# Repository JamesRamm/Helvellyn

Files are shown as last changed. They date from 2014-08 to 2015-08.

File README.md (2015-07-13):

Helvellyn
==========

KiCAD schematic and pcb files for the Helvellyn console project.

Helvellyn is a modular, DIY console design by Ramshackle Recording. 
PCB's for various modules will be available from www.ramshacklerecording.com

The backplane PCB for the console is released as an open source project for self-etching/manufacture and improvements, updates etc.

PCB's for the four-module backplane will also be available from Ramshackle Recording.

The Concept
============
The Helvellyn console system is based on the Eurocard and eurorack format and aims to be:

- Modular
- Expandable
- Analogue signal path
- Customisable

Each backplane PCB has space for four 7HP wide eurocard modules, or two 14HP modules.
Modules mate to the backplane via a 32-way DIN connector, which provides the following functionality:

- Two balanced inputs per module (I.e there are allowances for +, - and 0v on each input)
- A direct output (or 2 unbalanced outputs)
- 12 audio buses ('Normal' configuration will be 4 mono auxilliary buses, 3 stereo mix buses and 1 stereo master bus)
- +Ve, -Ve power buses (normally +/-16V)
- Four ground/0V buses (normally used as reference voltage for power, audio, relay/logic power and fader)
- A single, unbalanced output. Normally used to send audio to an external fader.

The backplane can be fixed to a standard 3U Eurorack such as:
http://uk.farnell.com/schroff/24563-131/subrack-3u-175mm-84hp/dp/1370391

With the Helvellyn system, it will be possible to build anything from a single 'lunchbox' rack of individual modules, to a large console with all the usual facilities.

Modules
==========
Ramshackle Recording is actively developing a set of modules which can be used to produce a small-format, high quality mixing desk.
The first modules to be released will be:

- EasyPSU: an 'onboard' PSU for powering a single rack
- Easy69: an easy-to-build high quality EQ, based on the famous Helios type 69.
- ISA-ish: A preamp. Something like the Focusrite ISA, but with modern components.

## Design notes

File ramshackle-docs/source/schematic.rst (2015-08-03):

.. _schematic

Schematic
============

Below is the schematic for the Easy69 module and also the backplane connections for the Helvellyn backplane/motherboard

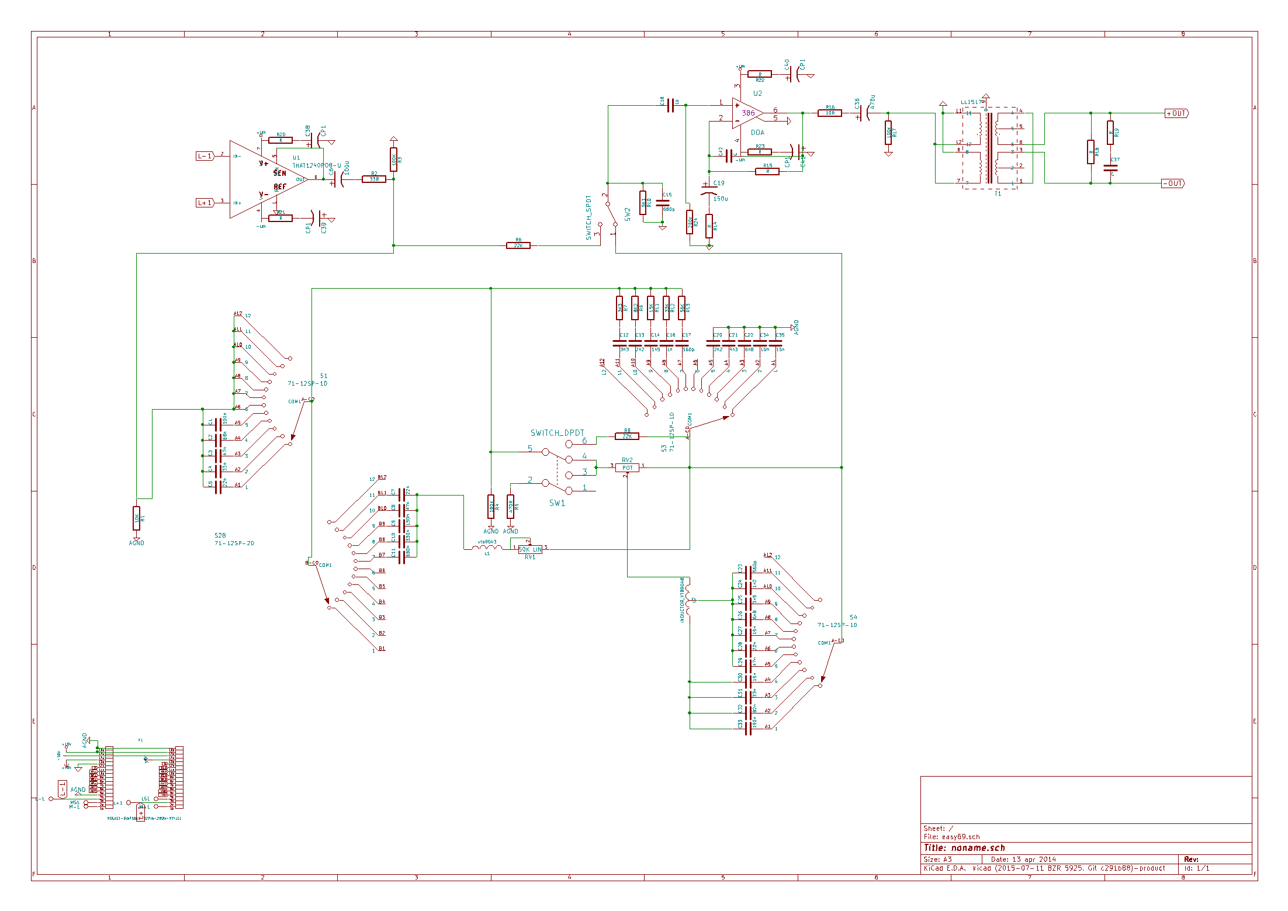
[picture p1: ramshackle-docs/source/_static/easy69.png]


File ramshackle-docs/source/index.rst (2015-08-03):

.. easy69 documentation master file, created by
   sphinx-quickstart on Sun Dec 14 18:03:30 2014.
   You can adapt this file completely to your liking, but it should at least
   contain the root `toctree` directive.

Easy69
==================================

Easy 69 is a 3-band inductor based EQ based on the classic Helios type 69. It is aimed as a relatively simple build with easy-to-find parts. 

Contents:

.. toctree::
   :maxdepth: 2
   
   schematic
   bom
   notes

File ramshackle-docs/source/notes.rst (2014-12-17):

.. _notes

Build Notes
==================================
Before starting anything, you should familiarise yourself with the schematics and board layout.
There are various choices to make when gathering components, such as which transformer and opamp to use. 
This decision will affect the value of some resistors and capacitors.

Opamps
------------------

The resistors R15 and R14 set the makeup gain for the opamp. 
The easy69 has approximately a 15dB insertion loss. Therefore R15 and R14 should be scaled such that 

.. math::
    20log(1 + R15/R14) =~ 15

An example value would be :math:`R15 = 25K` and :math:`R14 = 5K1`. These are good values to choose for 2520-style opamps.
There are of course numerous combinations of R14 and R15 that will give the correct gain and the best values to choose depends upon the opamp.
Usually the manufacturer/designer should be able to give you some kind of indication as to a good pairing.

C42 is a compensation cap, usually in the range 10 - 500pf. Some opamps already include a compensation cap, so you should check the datasheet as to whether this is necessary.

Transformers
------------------
Easy69 can take a Lundahl LL1517, Cinemag XXXX or Edcor XXXX transformer.
The resistor and capacitor XXXX form a zobel network which is required to dampen `ringing`in a transformer.
The correct values are dependent on the transformer and can usually be found via the datasheet or from the manufacturer.

Capacitor ranges: Panasonic ECQE(F) ECQV(?)
ECQE(B)

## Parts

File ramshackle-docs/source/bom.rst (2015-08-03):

.. _bom

Bill Of Materials
=====================

.. _capacitors:
Capacitors
------------
.. csv-table:: 
    :header: "Value", "Quantity", "Ref", "Link", "Note"    

    "560p",	2,	"C17 C23", `Farnell <http://uk.farnell.com/lcr-components/fscex-560pf-1-630v/cap-film-ps-560pf-630v-axial/dp/9520813?ost=9520813>`_,
    "680p",	1,	"C15",`Farnell <http://uk.farnell.com/wima/fkp2d006801d00jssd/cap-film-pp-680pf-100v-rad/dp/1005990?ost=1005990>`_,
    "1n",	1,"C16"
    "1n2",1,"C24","`Farnell <http://uk.farnell.com/wima/fkp2d011001d00hssd/cap-film-pp-1nf-100v-rad/dp/1890176>`_ `Mouser <http://uk.mouser.com/ProductDetail/Kemet/MMK5122J100J01L165TA18/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>`_","Alternately use pll combination of 680p and 560p"
    "1n5",1,"C14",`Farnell <http://uk.farnell.com/wima/fks2d011501a00kssd/cap-film-pet-1-5nf-100v-rad/dp/1005993?ost=1005993>`_
    "2n2",2,"C13 C20",`Farnell <http://uk.farnell.com/wima/fks2d012201a00kssd/cap-film-pet-2-2nf-100v-rad/dp/1005949?ost=1005949>`_,
    "3n3",1,"C12",`Farnell <http://uk.farnell.com/wima/fks2d013301a00kssd/cap-film-pet-3-3nf-100v-rad/dp/1005994?ost=1005994>`_,
    "3n9",1,"C25",`Mouser <http://uk.mouser.com/ProductDetail/Kemet/MMK5392J63J01L165TR18/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>`_,"Alternately use 3.98 = pll combination of 3n3 and 680pf"
    "4n3",1,"C21",`Mouser <http://uk.mouser.com/ProductDetail/Vishay/BFC237516432/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>`_,"Can also use 4n7 farnell #: 1890183	1890183"
    "6n8",2,"C22 C26",`Farnell <http://uk.farnell.com/wima/fks2d016801a00kssd/cap-film-pet-6-8nf-100v-rad/dp/1005997?ost=1005997>`_,
    "10n",1,"C34",`Farnell <http://uk.farnell.com/panasonic-electronic-components/ecqv1h103jl/cap-film-pet-10nf-50v-rad/dp/1669200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>`_,
    "15n",3,"C27 C30 C35",`Farnell <http://uk.farnell.com/panasonic-electronic-components/ecqv1h153jl/cap-film-pet-15nf-50v-rad/dp/1669202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>`_,
    "22n",3,"C5 C7 C28",`Farnell <http://uk.farnell.com/panasonic-electronic-components/ecqv1h223jl/cap-film-pet-22nf-50v-rad/dp/1669204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>`_,
    "33n",2,"C4 C31",`Farnell <http://uk.farnell.com/panasonic-electronic-components/ecqv1h333jl/cap-film-pet-33nf-50v-rad/dp/1854824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>`_,
    "47n",3,"C3 C8 C29",`Farnell <http://uk.farnell.com/panasonic-electronic-components/ecqv1h473jl/cap-film-pet-47nf-50v-rad/dp/1744826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>`_,
    "68n",1,"C2",`Farnell <http://uk.farnell.com/panasonic-electronic-components/ecqv1h683jl/cap-film-pet-68nf-50v-rad/dp/1744827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>`_,
    "82n",1,"C32",`Farnell <http://uk.farnell.com/panasonic-electronic-components/ecqv1h823jl/cap-film-pet-82nf-50v-rad/dp/1854827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>`_,
    "100n",1,"C1",`Farnell <http://uk.farnell.com/wima/mks0c031000c00jssd/cap-film-pet-100nf-63v-rad/dp/1890126?ost=1890126>`_,
    "150n",2,"C9 C33",`Farnell <http://uk.farnell.com/wima/mks4d031502b00kssd/cap-film-pet-150nf-100v-rad/dp/1890155?ost=1890155>`_,
    "330n",1,"C10",`Farnell <http://uk.farnell.com/wima/mks2c033301c00jssd/cap-film-pet-330nf-63v-rad/dp/1890136?ost=1890136>`_,
    "680n",1,"C11",`Farnell <http://uk.farnell.com/wima/mks2c036801e00kssd/cap-film-pet-680nf-63v-rad/dp/1006039?ost=1006039>`_,
    "1u",	1,"C18",`Farnell <http://uk.farnell.com/wima/mks2c041001f00jssd/cap-film-pet-1uf-63v-rad/dp/1890139?ost=1890139>`_,
    "100u",1,"C6",`Farnell <http://uk.farnell.com/panasonic-electronic-components/ecea1vn101u/cap-alu-elec-100uf-35v-rad/dp/2326034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>`_,
    "150u",1,"C19",`Farnell <http://uk.farnell.com/panasonic-electronic-components/eeufr1e151/cap-alu-elec-150uf-25v-rad/dp/1907236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>`_,
    "TBD",2,"C37 C42",
    "470u",1,"C36",`Farnell <http://uk.farnell.com/panasonic-electronic-components/eca1ehg471/cap-alu-elec-470uf-25v-rad/dp/9692843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>`_,
    "330u",4,"C38 C39 C40 C41",`Farnell <http://uk.farnell.com/panasonic-electronic-components/eca1vam331x/cap-alu-elec-330uf-35v-rad/dp/8767270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>`_,

.. _resistors:
Resistors
-----------
.. csv-table::
    :header: "Value", "Quantity", "Ref", "Link", "Note"  
    
    10R,	1,	R16,	`Farnell <http://uk.farnell.com/te-connectivity/lr0204f10r/resistor-metal-10r-0-25w-1/dp/2329856?ost=2329856>`_,
    33R,	1,	R2,	`Farnell <http://uk.farnell.com/te-connectivity/lr0204f33r/resistor-metal-33r-0-25w-1/dp/2329924?ost=2329924>`_,
    470R, 1,	R5,	`Farnell <http://uk.farnell.com/te-connectivity/lr0204f470r/resistor-metal-470r-0-25w-1/dp/2329942?ost=2329942>`_,
    3K3,	1,	R7,	`Farnell <http://uk.farnell.com/te-connectivity/lr0204f3k3/resistor-metal-3k3-0-25w-1/dp/2329934?ost=2329934>`_,
    5K1,	1,	R10,	`Farnell <http://uk.farnell.com/te-connectivity/lr0204f5k1/resistor-metal-5k1-0-25w-1/dp/2329957?ost=2329957>`_,
    8K2,	1,	R9,	`Farnell <http://uk.farnell.com/te-connectivity/lr0204f8k2/resistor-metal-8k2-0-25w-1/dp/2329981?ost=2329981>`_,
    10K,	1,	R1,	`Farnell <http://uk.farnell.com/multicomp/mf25-10k/resistor-10k-0-25w-1/dp/9341110?ost=9341110>`_,9341110,
    15K,	1,	R11,	`Farnell <http://uk.farnell.com/te-connectivity/lr0204f15k/resistor-metal-15k-0-25w-1/dp/2329873?ost=2329873>`_,
    22K,	2,	R6 R8,	`Farnell <http://uk.farnell.com/te-connectivity/lr0204f22k/resistor-metal-22k-0-25w-1/dp/2329901?ost=2329901>`_,
    33K,	1,	R12,	`Farnell <http://uk.farnell.com/te-connectivity/lr0204f33k/resistor-metal-33k-0-25w-1/dp/2329922?ost=2329922>`_,
    56K,	1,	R13,	`Farnell <http://uk.farnell.com/te-connectivity/lr0204f56k/resistor-metal-56k-0-25w-1/dp/2329954?ost=2329954>`_,
    100K,	1,	R3 R17,`Farnell <http://uk.farnell.com/te-connectivity/lr0204f100k/resistor-metal-100k-0-25w-1/dp/2329853?ost=2329853>`_,
    180K	,1,	R4,`Farnell <http://uk.farnell.com/te-connectivity/lr0204f180k/resistor-metal-180k-0-25w-1/dp/2329880?ost=2329880>`_,
    200k	,1,	R24,`Farnell <http://uk.farnell.com/te-connectivity/lr0204f200k/resistor-metal-200k-0-25w-1/dp/2329895?ost=2329895>`_,
    TBD,	8,	R14 R15 R18 R19 R20 R21 R22 R23,

.. _pots:
Potentiometers/Switches
------------------------------
.. csv-table::
    :header:  "Value", "Quantity", "Ref", "Link", "Note"  

    50K, LIN	1,	RV1,	1517306
    25K, Lin	1,	RV2,	8557586
    71-12SP-1D,	3,	S1 S3 S4,	
    71-12SP-2D,	1,	S2,	
    SWITCH_DPDT,	1,	SW1, 9473394
    SWITCH_SPDT,	1,	SW2, 9473378
    
.. _trafo:
Transformers/Inductors 
-----------------------------
.. csv-table::
    :header:  "Value", "Quantity", "Ref", "Link", "Note"     
    
    Carnhill VTB9043,	1,	L1,,	Available from audiomaintenance	
    Carnhill VTB9048,	1,	L2,,	Available from audiomaintenance	
    LL1517,	1,	T1,	

.. _opamps:
Opamps
----------
.. csv-table::
    :header:  "Value", "Quantity", "Ref", "Link", "Note"   

    THAT1240PO8-U, 1, U1,	1354147
    DOA,	1,	U2,	
    
.. _connectors:
Connectors
--------------
.. csv-table::
    :header:  "Value", "Quantity", "Ref", "Link", "Note"   

    Male DIN41612,	1,	1656157
    Female DIN41612,	1, 1656165

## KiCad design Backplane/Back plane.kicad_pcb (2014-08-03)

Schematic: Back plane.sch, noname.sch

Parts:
L+1, L+2, L+3, L+4: CONN_1
L-1, L-2, L-3, L-4: CONN_1
LS1, LS2, LS3, LS4: CONN_1
M+1, M+2, M+3, M+4: CONN_1
M-1, M-2, M-3, M-4: CONN_1
MS1, MS2, MS3, MS4: CONN_1
P1, P2, P3, P4, P5, P6, P7, P8, P9, P10, P11, P12, P13, P14, P15, P16, P17, P18, P19, P20, P21, P22, P23, P24, P25, P26, P27, P28, P29, P30, P31, P32, P33, P34, P35, P36, P37, P38, P39, P40, P41, P42, P43, P44, P45, P46, P47, P48, P49, P50, P51, P52: CONN_1
X1, X2, X3, X4: SOCKET-DIN41612-32PIN-2ROW-STYLE1

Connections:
+5V: P22.1, P43.1, X1.13b, X2.13b, X3.13b, X4.13b
+16V: P10.1, P31.1, X1.15a, X1.15b, X2.15a, X2.15b, X3.15a, X3.15b, X4.15a, X4.15b
+48V: P12.1, P33.1, X1.13a, X2.13a, X3.13a, X4.13a
+OUT1: P8.1, X1.5b
+OUT2: P1.1, X2.5b
+OUT3: P5.1, X3.5b
+OUT4: P3.1, X4.5b
-16V: P11.1, P32.1, X1.14a, X1.14b, X2.14a, X2.14b, X3.14a, X3.14b, X4.14a, X4.14b
-OUT1: P7.1, X1.4b
-OUT2: P2.1, X2.4b
-OUT3: P6.1, X3.4b
-OUT4: P4.1, X4.4b
AGND: P9.1, P30.1, X1.16a, X1.16b, X2.16a, X2.16b, X3.16a, X3.16b, X4.16a, X4.16b
AUX1: P19.1, P40.1, X1.6a, X2.6a, X3.6a, X4.6a
AUX2: P28.1, P49.1, X1.7b, X2.7b, X3.7b, X4.7b
AUX3: P20.1, P41.1, X1.5a, X2.5a, X3.5a, X4.5a
AUX4: P29.1, P50.1, X1.6b, X2.6b, X3.6b, X4.6b
B1_L: P15.1, P36.1, X1.10a, X2.10a, X3.10a, X4.10a
B1_R: P24.1, P45.1, X1.11b, X2.11b, X3.11b, X4.11b
B2_L: P16.1, P37.1, X1.9a, X2.9a, X3.9a, X4.9a
B2_R: P25.1, P46.1, X1.10b, X2.10b, X3.10b, X4.10b
B3_L: P17.1, P38.1, X1.8a, X2.8a, X3.8a, X4.8a
B3_R: P26.1, P47.1, X1.9b, X2.9b, X3.9b, X4.9b
B4_L: P18.1, P39.1, X1.7a, X2.7a, X3.7a, X4.7a
B4_R: P27.1, P48.1, X1.8b, X2.8b, X3.8b, X4.8b
FG: P14.1, P35.1, X1.11a, X2.11a, X3.11a, X4.11a
FS1: P44.1, X2.12b
FS2: P23.1, X4.12b
FS3: P51.1, X1.12b
FS4: P52.1, X3.12b
GND: P13.1, P34.1, X1.12a, X2.12a, X3.12a, X4.12a
GNDA: P21.1, P42.1, X1.4a, X2.4a, X3.4a, X4.4a
L+1: L+1.1, X1.2b
L+2: L+2.1, X2.2b
L+3: L+3.1, X3.2b
L+4: L+4.1, X4.2b
L-1: L-1.1, X1.3a
L-2: L-2.1, X2.3a
L-3: L-3.1, X3.3a
L-4: L-4.1, X4.3a
unnamed: M-3.1, X3.1a
unnamed: M+3.1, X3.1b
unnamed: LS3.1, X3.3b
unnamed: MS3.1, X3.2a
unnamed: M+4.1, X4.1b
unnamed: MS4.1, X4.2a
unnamed: M-4.1, X4.1a
unnamed: LS4.1, X4.3b
unnamed: MS2.1, X2.2a
unnamed: M-2.1, X2.1a
unnamed: M+2.1, X2.1b
unnamed: LS2.1, X2.3b
unnamed: MS1.1, X1.2a
unnamed: LS1.1, X1.3b
unnamed: M+1.1, X1.1b
unnamed: M-1.1, X1.1a

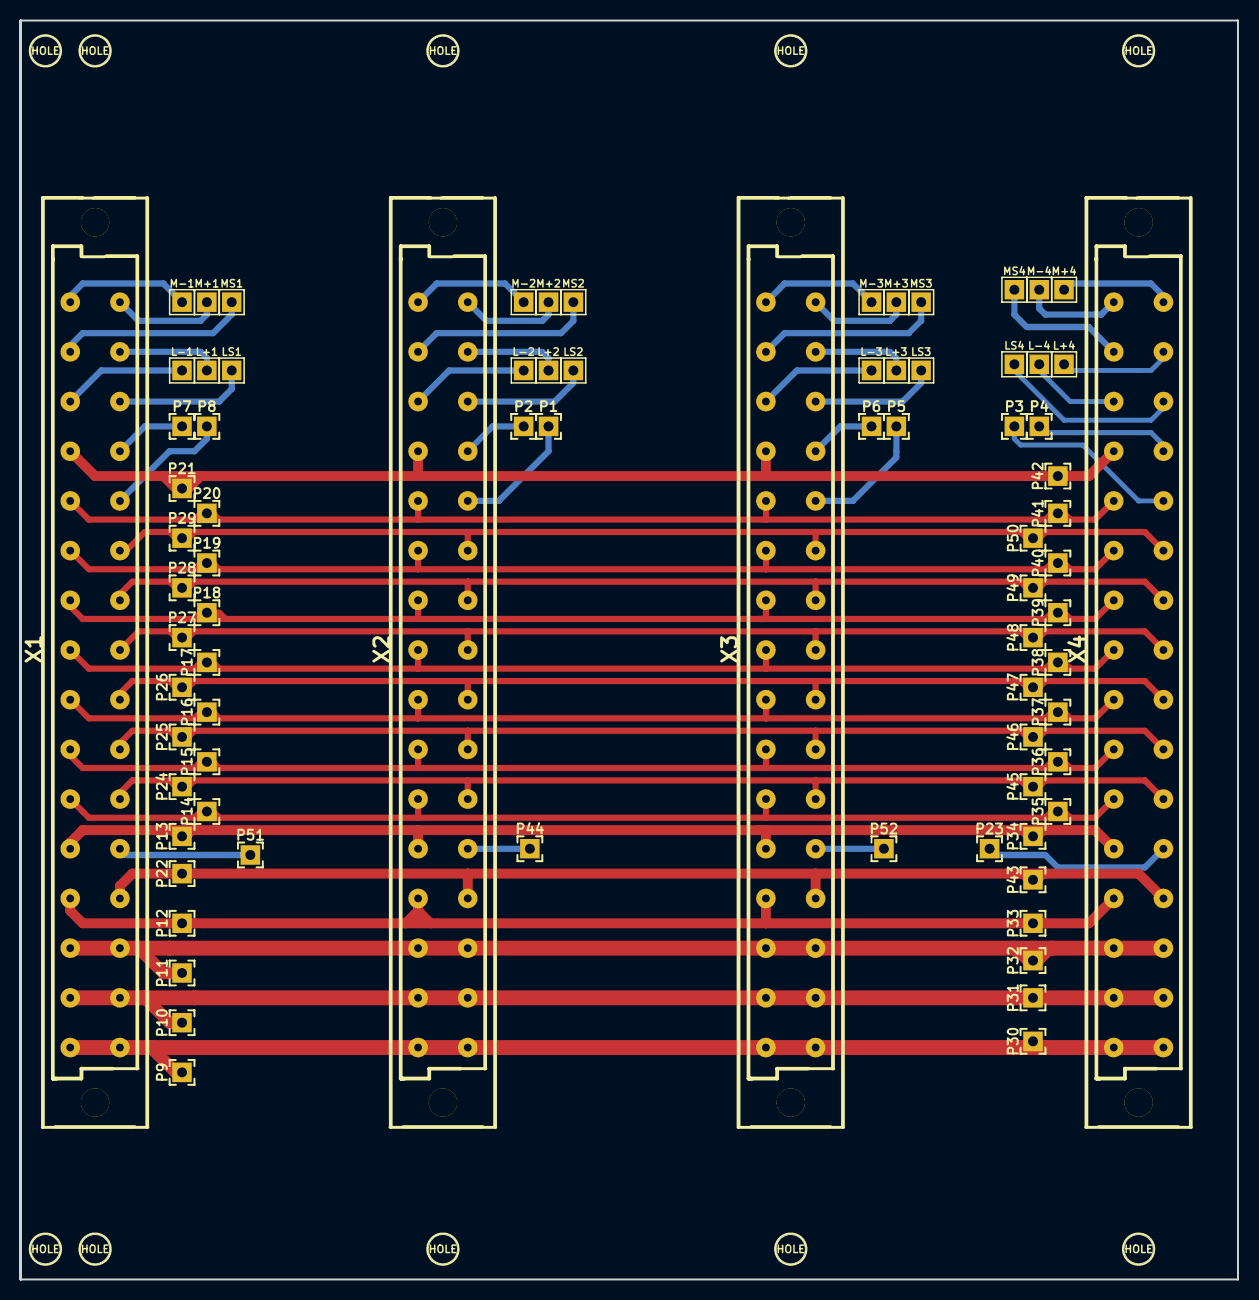
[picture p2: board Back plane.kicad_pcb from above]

Board: 2 copper layers, 124.5 x 128.7 mm, 90 parts (0 on the bottom side), 56 nets.

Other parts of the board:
HOLE: Val**; HOLE_30_nopad
HOLE#2, HOLE#3, HOLE#4, HOLE#5, HOLE#6, HOLE#7, HOLE#8, HOLE#9, HOLE#10: Val**; HOLE_30_nopad

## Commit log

2014-08-03 Initial commit
    Initial commit of the backplane files.
    The Helvellyn backplane provides communication between modules, power
    buses etc...
    [Back plane.kicad_pcb, Back plane.sch]
2015-08-03 Added schematic
2015-08-03 Better BOM title
